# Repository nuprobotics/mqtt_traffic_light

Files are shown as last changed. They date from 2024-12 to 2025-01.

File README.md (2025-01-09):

Review Assignment Due Date (https://classroom.github.com/a/cU98Cs0g)
# Robotics NUP
## MQTT Traffic Light

### Overview
A Traffic light, managed via mqtt protocol based on ESP32C3 controller and WS2821B LED strip.

###  Problem Statement
We need a managed traffic light for our polygon in smart city lab.

### Objectives
- The system has to be stable.
- The traffic light configuration must be changable with minimal human intervention.
- The system must be scalable.

### Features
- Modular structure (interchangable 5,4 and 3 segmented traffic light heads)
- Wifi as a network interface
- Powered by Type-C connector 

### Hardware
ESP32C3
WS2812B 60LED/M  
PETG plastic

### Timeline
- Phase 1 (8.11 - 22.11): MQTT brocker running on a server in the lab, esp32 flashes an LED when triggered through MQTT
- Phase 2 (22.11 - 6.12): The phisical traffic light is designed and assembled
- Phase 3 (6.12 - 20.12): The traffic light is stably running, managed through an MQTT broker

### Team
- Vladimir Shtarev
- Innokentii Meleshchenko

### Risks and Mitigation Strategies

At least two!

| Risk | Impact | Probability | Mitigation Strategy |
| ---| --- | --- | ---|
| No native MQTT support for ESP32C3 | High | Medium | Port MQTT for ESP32 |
| No native WS2812B support for ESP32C3 | High | Low | Port WS2812B driver for ESP32 |
### Success Criteria
- The Traffic light works as an mqtt device
- The traffic light's configuration can be changed in less than 5 minutes
- The traffic light works reliably (no fails during 1 hour continuous test)

### Appendix
The hardware is provided by Vladimir Shtarev

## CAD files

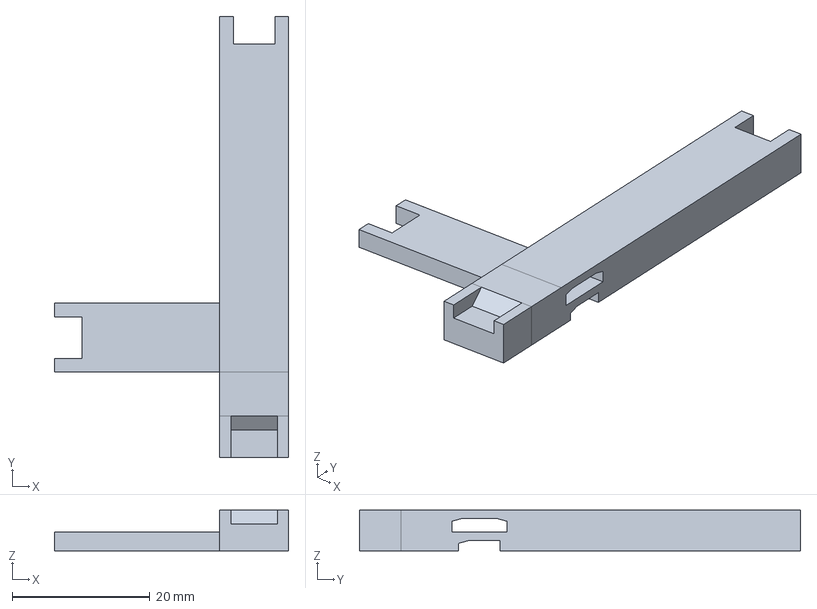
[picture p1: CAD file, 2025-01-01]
CAD_models/traffic_light_head_bare_left.FCStd
34.0 x 64.0 x 5.90 mm

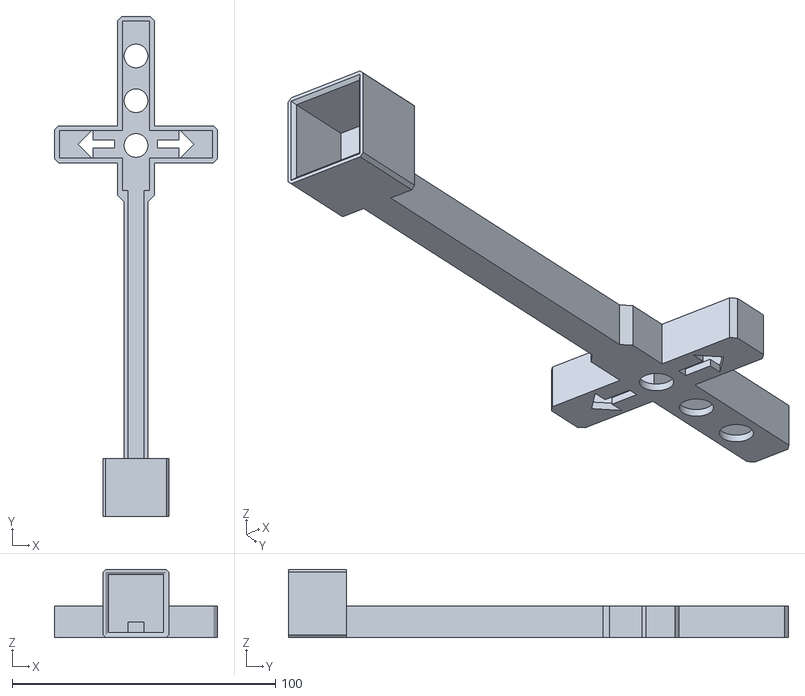
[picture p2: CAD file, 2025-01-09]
Mesh_models/traffic_light_head_case_p1_both.stl
62.0 x 190.0 x 26.0

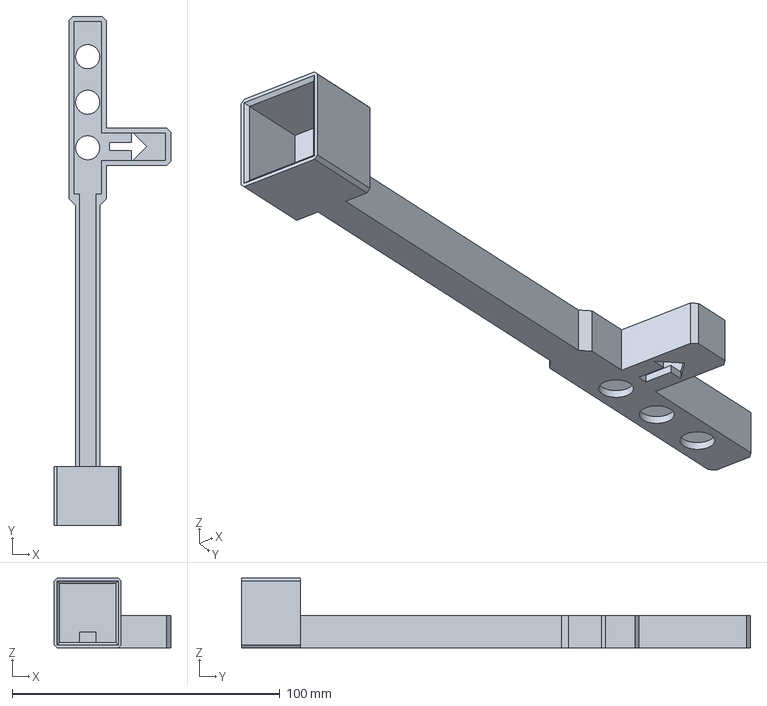
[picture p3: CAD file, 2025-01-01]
CAD_models/traffic_light_head_case_p1_left.FCStd
43.5 x 190.0 x 26.0 mm

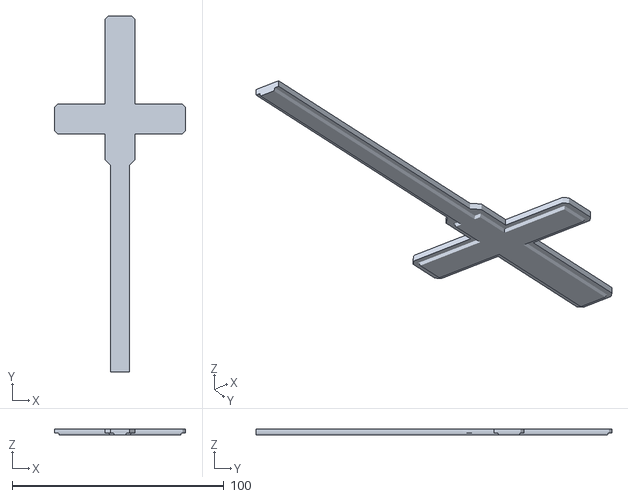
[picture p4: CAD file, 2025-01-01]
Mesh_models/traffic_light_head_case_p2_both.stl
62.0 x 168.0 x 3.00

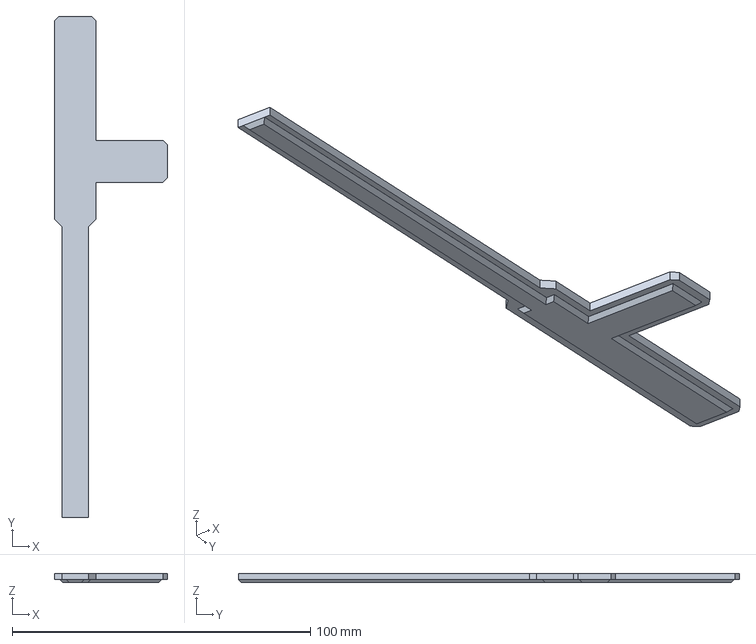
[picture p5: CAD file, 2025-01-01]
CAD_models/traffic_light_head_case_p2_left.FCStd
38.0 x 168.0 x 3.00 mm

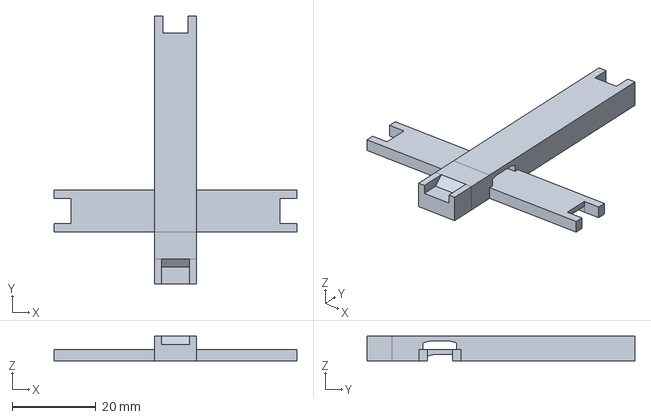
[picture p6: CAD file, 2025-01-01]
CAD_models/traffic_light_head_bare_both.FCStd
58.0 x 64.0 x 5.90 mm

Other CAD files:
Mesh_models/traffic_light_head_case_p2_right.stl
CAD_models/traffic_light_head_case_p1_right.FCStd
Mesh_models/traffic_light_head_bare_left.stl
CAD_models/traffic_light_head_case_p2_both.FCStd
Mesh_models/traffic_light_head_case_p1_left.stl
Mesh_models/traffic_light_head_case_p1_right.stl
CAD_models/traffic_light_head_case_p1_both.FCStd
Mesh_models/traffic_light_head_bare_both.stl
CAD_models/traffic_light_head_case_p2_right.FCStd
Mesh_models/traffic_light_head_bare_right.stl
CAD_models/traffic_light_head_bare_right.FCStd
Mesh_models/traffic_light_head_case_p2_left.stl
CAD_models/base.FCStd
CAD_models/base_lid.FCStd
Mesh_models/base.stl
Mesh_models/base_lid.stl

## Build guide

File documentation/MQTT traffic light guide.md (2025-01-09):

# MQTT Traffic light

## Opening the project in Clion

In order to open the project you have to install PlatformIO core (simply `run $sudo python3 mqtt_traffic_light/Firmware/get-platformio.py`, then install the PlatformIO Clion plugin. If you have any troubles, check official PlatformIO documentation (https://docs.platformio.org/en/latest/core/installation/index.html).
After you have successfully installed PlatformIO core and PlatformIO plugin in CLion, go to Clion tools menu->PlatformIO->PlatformIO Home, go to the PlatformIO Home web page -> Open project -> select mqtt_traffic_light/Firmware -> open -> close the file manager. After that you can open the project in Clion as usual. To build and flash the firmware, simply use the run button in Clion (make sure you have your ESP32C3 connected with a USB-C cable, if it does not work, try pressing the "boot" button before plugging in the cable)

## Project structure

The firmware is built on Arduino framework, so in the main.cpp there are setup() and loop(). There are two classes: TrafficLight and MqttController. In the TrafficLight all the basic logic of state and config is implemented. In the MqttController all the mqtt logic is implemented. 

## Traffic light logic
Traffic light has four possible configurations: MAIN_3_STATE, MAIN_PLUS_RIGHT, MAIN_PLUS_LEFT, MAIN_PLUS_BOTH. As follows from the naming it has either 3 main lights, 1 or 2 side arrows. The main lights can be set to red, yellow and green, while the arrows can be set to off or green. The control is implemented with Adafruit NeoPixel library for WS2812B led strip.

## MQTT logic 
When traffic light is booted, it connects to the Wifi then connects to MQTT broker. As soon as it is connected to the broker it publishes a message to the init topic and collects responses with IDs of active traffic lights during specified timeframe. After that it picks an ID=n+1, where n is the greatest id it collected, that is later published to the same topic. After the traffic light selected it's ID, it subscribes to it's control topic and starts usual operation loop (monitors init topic and announces it's id on request, monitors control topic and responds to requests of changing the configuration or the state.) 
The wifi SSID, password, mqtt address and port, mqtt init topic and mqtt control topic base, as well as the timeframe of recieving id announce responds is specified in the `mqtt_traffic_light/Firmware/src/Config.h` file. 
If you want to use mqtt credentials for connection, simply uncomment corresponding lines in the Config.h file and put your credentials in there, TLS certificate auth is not yet supported.

## Controlling individual traffic lights
To change the config of a specific traffic light, you have to publish a message to the corresponding mqtt control topic:
`SET_CONFIG MAIN_3_STATE` / `SET_CONFIG MAIN_PLUS_RIGHT` /  `SET_CONFIG MAIN_PLUS_LEFT` / `SET_CONFIG MAIN_PLUS_BOTH`

To change the state of a specific traffic light, you have to publish a message to the corresponding mqtt control topic: 
`SET MAIN RED`/`YELLOW`/`GREEN LEFT OFF`/`GREEN RIGHT OFF`/`GREEN`
e.g. `SET MAIN RED LEFT OFF  RIGHT GREEN`

If the state does not match the config, parts not present in the config (e.g. one or both arrows) will simply not be applied, but the others will be. So if you notice, that setting the arrow state does not apply, check the traffic light configuration.

## Assembly
### First you need to get the required hardware:

1. ~82mm (5 LEDs) of WS2812B LED strip 60LED/M
2. ~0.5 meter of thin wire
3. ~130-150mm 3-wire XH2.54 male cable
4. 3-pin XH2.54 female connector
5. 4 M3x10 screws
6. 4 M3 nuts
7. ESP32C3 supermini 
8. 3d-printed parts from mqtt_traffic_light/Mesh_models (i used PETG with 0.6mm nozzle, all parts, except for trafficlight_head_case_p1 are printed without supports). Make sure to set a pause, when printing base.stl, to put the screws inside before the gaps are covered. 
9. Hot glue 
10.  Soldering tools
11. Super glue 
12. A little bit of Double-sided tape
13. A little bit of regular tape

### Assembly steps:
1. Glue the **XH2.54 female connector** into the **base_lid** part, so it is flush with the bottom side of it. 
2. Solder the  **XH2.54 female connector** to the 5V, GND, GPIO4 pins of the **ESP32C3**. 
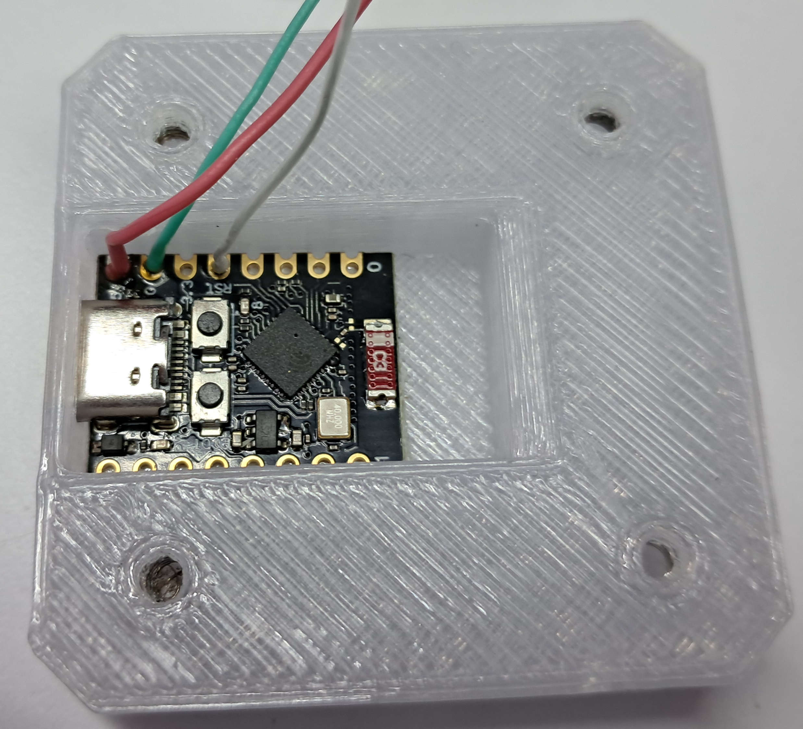
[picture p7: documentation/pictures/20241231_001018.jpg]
3. Use double-sided tape to fix the **ESP32C3** in the **base** part, so the USB-C port is inside the corresponding slot and is easily accessible from the outside.
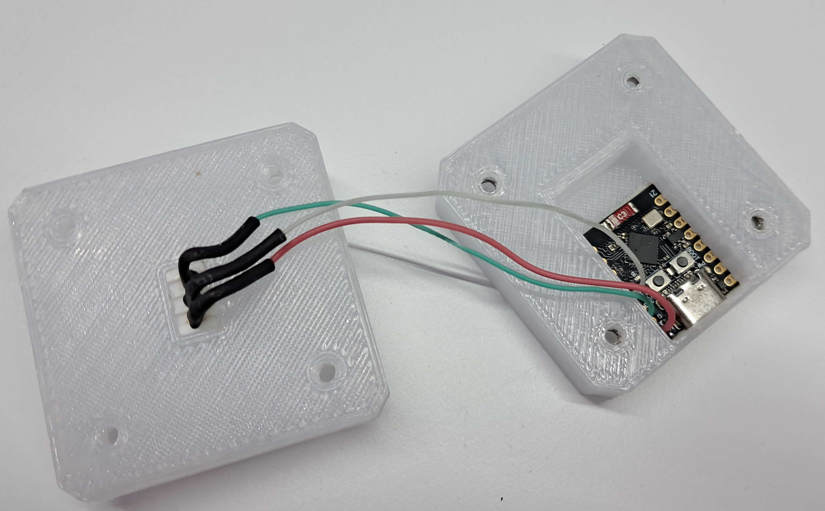
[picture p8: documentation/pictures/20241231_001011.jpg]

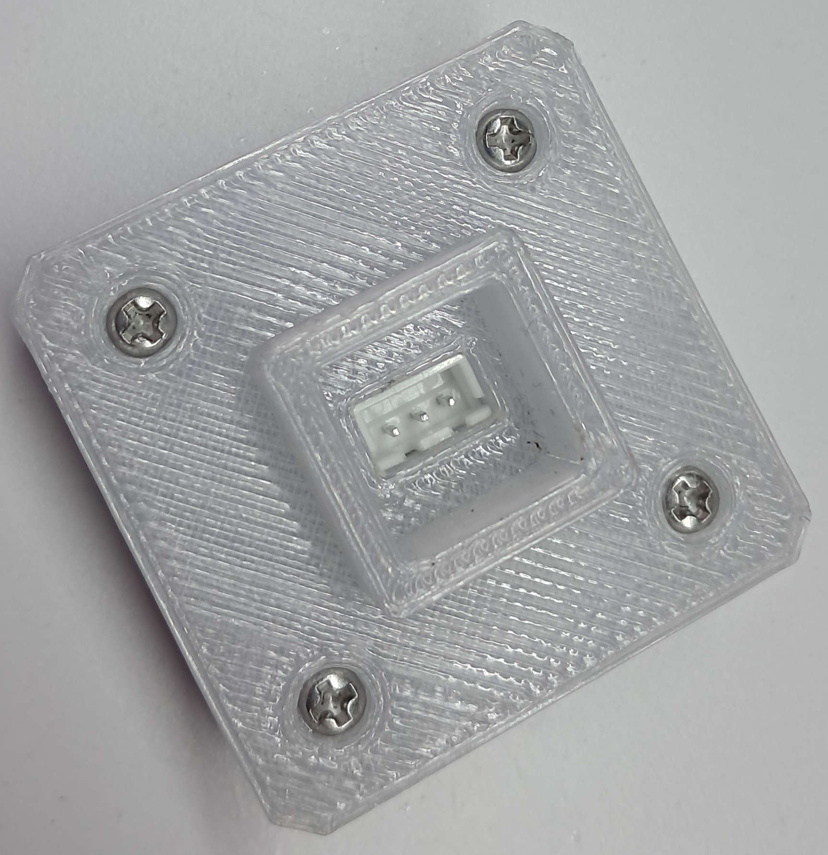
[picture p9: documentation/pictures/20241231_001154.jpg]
4. Screw the **base_lid** to the **base** part.
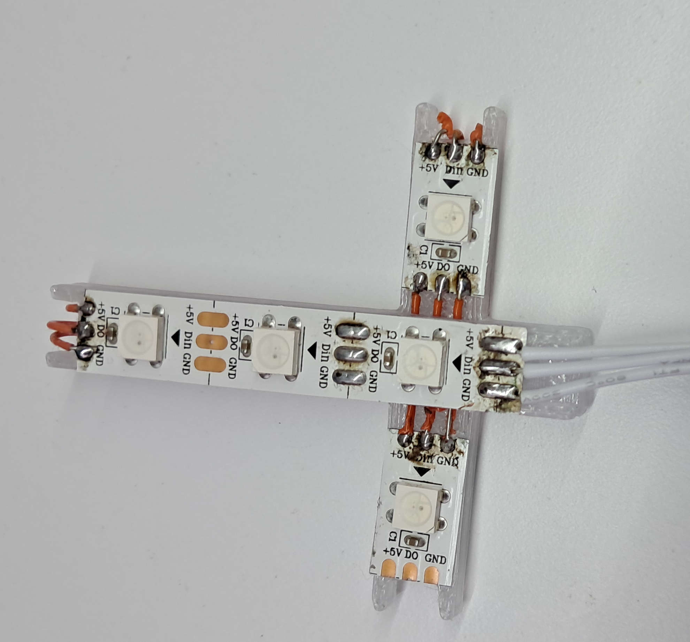
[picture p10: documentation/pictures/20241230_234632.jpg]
5. Asseble the core of the traffic light head using the **traffic_light_head_bare** part, WS2812B, thin wire and the **3-wire XH2.54 male cable**. Make sure the pinout of all the **WS2812B** strips matches the pinout of the **ESP32C3** with the **XH2.54 female connector**.
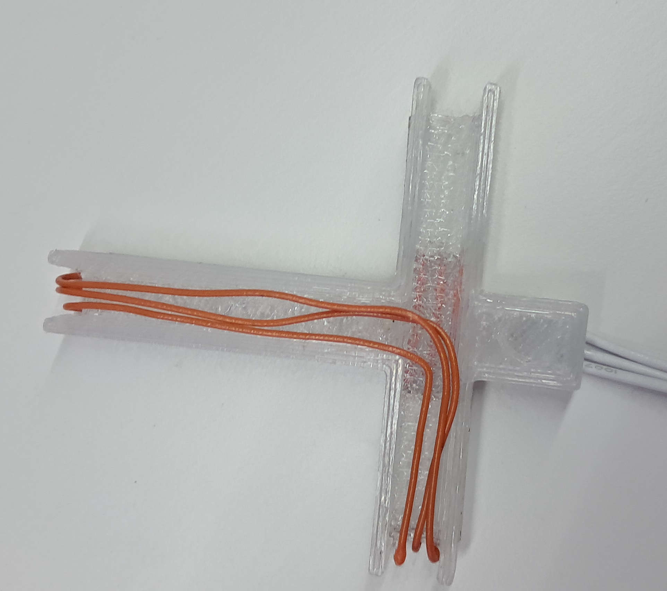
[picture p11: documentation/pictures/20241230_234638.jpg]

6. Cover the holes for the lights of the **traffic_light_head_case_p1** with regular tape, and pour hot glue in the holes. The hot glue shoul be flush with both sides of the part. Wait for the hot glue to cool down.
7. Insert the core of the traffic light head into the **traffic_light_head_case_p1** part. It does not matter if it is not alligned perfectly, it is also not supposed to be flush with the back side of the **traffic_light_head_case_p1**.
8. Insert the **traffic_light_head_case_p2** into the **traffic_light_head_case_p1**, if it is not fixed by friction, use some super glue. 
9. Connect the **3-wire XH2.54 male cable** to the **XH2.54 female connector**. Put the Traffic light head fixture onto the **base_lid**. 
10.  Power on the Traffic light and check if it works correctly (use UART monitor for logs and send a state command to the corresponding topic to check the LEDS. If the LEDS do not turn on, but the logs are ok and you have sent the change state command, probably you have faulty wiring.).

11.* The **traffic_light_head_bare**, **traffic_light_head_case_p1** and **traffic_light_head_case_p2** are supposed to be selected based on the traffic light configuration you want to use: e.g. for MAIN_PLUS_BOTH use parts with "both" at the end. The wiring should be changed accordingly: For single arrow configs, the arrow data input is connected directly to the main strip output and for both arrows, the right one is connected first, and the left one is connected to the right one.

## Congratulations, now you can build your own small-scale traffic light system with as many different traffic lights as you want.

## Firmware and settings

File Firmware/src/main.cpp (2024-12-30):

#include "TrafficLight.h"
#include "MqttController.h"

TrafficLight trafficLight(TrafficLightConfiguration::MAIN_PLUS_BOTH);
MqttController mqttController(trafficLight);

void setup() {
    Serial.begin(115200);
    delay(1000);
    pinMode(LED_PIN, OUTPUT);
    mqttController.begin();
    Serial.println("Finished setup, starting main loop...");
}

void loop() {
    mqttController.loop();
}

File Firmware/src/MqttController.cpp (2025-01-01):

#include "MqttController.h"

MqttController::MqttController(TrafficLight& trafficLight)
    : m_light(trafficLight),
      m_mqttClient(m_wifiClient),
      m_trafficLightId(0),
      m_isActive(false),
      m_initStartTime(0)
{
    // Empty
}

void MqttController::begin() {
    connectWiFi();

    m_mqttClient.setServer(MQTT_ADDRESS, MQTT_PORT);
    // Attach the callback function for incoming MQTT messages
    m_mqttClient.setCallback([this](const char* topic, const byte* payload, const unsigned int length){
        this->onMqttMessage(topic, payload, length);
    });

    // Start the ID negotiation
    m_isActive = false;
    m_initStartTime = millis();
    m_knownIds.clear();
    m_trafficLightId = 0;  // Means we don't have an ID yet

    connectMQTT();
    // Publish a message saying we're NEW and listening for existing IDs
    publishInitRequest();
}

void MqttController::loop() {
    // Maintain MQTT connection
    if (!m_mqttClient.connected()) {
        connectMQTT();
    }
    m_mqttClient.loop();
    // If we aren't active yet, check if we need to finalize ID assignment
    if (!m_isActive) {
        const unsigned long elapsed = millis() - m_initStartTime;
        if (elapsed >= ID_COLLECTION_TIME_MS) {
            checkAndAssignId();
        }
    }
}
// Example: using ESP32's chip-specific ID / MAC
String MqttController::generateMqttClientId() {
    // For ESP32 Arduino, you can get chip ID or MAC
    // In a typical ESP32 (not ESP32-C3), we might do something like:
    //   uint64_t chipid = ESP.getEfuseMac();
    // For ESP32-C3, you can read the MAC similarly:

    uint8_t mac[6];
    esp_read_mac(mac, ESP_MAC_WIFI_STA);  // read station mac
    char buf[30];
    snprintf(buf, sizeof(buf),
             "TrafficLight_%02X%02X%02X%02X%02X%02X",
             mac[0], mac[1], mac[2], mac[3], mac[4], mac[5]);
    return {buf};
}

void MqttController::connectWiFi() {
    Serial.print("Connecting to Wi-Fi: ");
    Serial.print(WIFI_SSID);

    char ssid[] = WIFI_SSID;
    char passwd[] = WIFI_PASSWD;
    WiFi.begin(ssid, passwd);

    while (WiFiClass::status() != WL_CONNECTED) {
        delay(500);
        Serial.print(".");
    }
    Serial.println(".");
    Serial.println("Wi-Fi connected.");
    Serial.print("IP address: ");
    Serial.println(WiFi.localIP());
}

void MqttController::connectMQTT() {
    while (!m_mqttClient.connected()) {
        Serial.print("Attempting MQTT connection to ");
        Serial.print(MQTT_ADDRESS);
        Serial.print("...");
        String clientId = generateMqttClientId();
        Serial.print("ClientID: ");
        Serial.println(clientId);


        #ifndef MQTT_LOGIN
        // Connect without auth
        if (m_mqttClient.connect(clientId.c_str())) {
            Serial.println("connected!");
            // Subscribe to the init topic unconditionally (we need to respond to new lights)
            m_mqttClient.subscribe(MQTT_INIT_TOPIC);
        } else {
            Serial.print("failed, rc=");
            Serial.print(m_mqttClient.state());
            Serial.println("; trying again in 2 seconds");
            delay(2000);
        }
        #else
        // Connect with auth from Config.h
        if (m_mqttClient.connect(clientId.c_str(), MQTT_LOGIN, MQTT_PASSWORD)) {
            Serial.println("connected!");
            // Subscribe to the init topic unconditionally (we need to respond to new lights)
            m_mqttClient.subscribe(MQTT_INIT_TOPIC);
        } else {
            Serial.print("failed, rc=");
            Serial.print(m_mqttClient.state());
            Serial.println("; trying again in 2 seconds");
            delay(2000);
        }
        #endif
    }
}

void MqttController::onMqttMessage(const char* topic, const byte* payload, const unsigned int length) {
    const String topicStr(topic);
    String message;
    for (unsigned int i=0; i<length; i++) {
        message += static_cast<char>(payload[i]);
    }

    // If this is the init topic
    if (topicStr == MQTT_INIT_TOPIC) {
        processInitMessage(message);
    }
    // If it's our control topic
    else if (m_isActive) {
        // Our control topic is something like: "trafficlights/control/<id>"
        const String controlTopic = String(MQTT_CONTROL_TOPIC) + String(m_trafficLightId);
        if (topicStr == controlTopic) {
            processControlMessage(message);
        }
    }
}

// We publish a "NEW" message so active lights will respond with their ID
void MqttController::publishInitRequest() {

    // For instance: "NEW"
    // You could embed your MAC address or partial ID for reference
    m_mqttClient.publish(MQTT_INIT_TOPIC, "NEW");
    // Also subscribe to the init topic (to see active lights responding)
    m_mqttClient.subscribe(MQTT_INIT_TOPIC);
    Serial.println("[MQTT] Published init request: NEW");
    Serial.println("Waiting for init responses...");
}

// We respond to another light's "NEW" request with "ACTIVE_ID=<myId>"
void MqttController::publishInitResponse() {
    if (!m_mqttClient.connected() || !m_isActive) return;
    char msg[32];
    snprintf(msg, sizeof(msg), "ACTIVE_ID=%d", m_trafficLightId);
    m_mqttClient.publish(MQTT_INIT_TOPIC, msg);
    Serial.print("[MQTT] Published init response: ACTIVE_ID=");
    Serial.println(m_trafficLightId);
}

void MqttController::processInitMessage(const String& message) {
    // If we see "NEW" from someone else, and we are active, we should respond with our ID
    if (message == "NEW") {
        if (m_isActive) {
            // respond with "ACTIVE_ID=<myId>"
            Serial.println("[MQTT] Received init request, responding...");
            publishInitResponse();
        }
    }
    // If we see something like "ACTIVE_ID=3" from an existing light while we are collecting IDs
    else if (message.startsWith("ACTIVE_ID=")) {
        const String idPart = message.substring(9); // get the substring after 'ACTIVE_ID='
        const int existingId = idPart.toInt();
        Serial.print("[MQTT] Received init response, id announced: ");
        Serial.println(existingId);
        m_knownIds.push_back(existingId);
        Serial.print("[MQTT] Got active ID, added to known ids: ");
        Serial.println(existingId);
    }
}

void MqttController::checkAndAssignId() {
    // We have finished collecting IDs, so pick the largest + 1
    // If no known IDs, we become ID=1
    int maxId = -1;
    for (int id : m_knownIds) {
        Serial.println(id);
        if (id > maxId) maxId = id;
    }
    m_trafficLightId = maxId + 1;
    m_isActive = true;

    // Now subscribe to our control topic
    subscribeToControlTopic();

    Serial.print("[MQTT] Assigned new ID: ");
    Serial.println(m_trafficLightId);
    publishInitResponse();
}
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

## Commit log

2024-11-22 added datasheet on esp32 C3
2024-11-23 designed the base of the traffic light
    [base.FCStd, base.stl, base_lid.FCStd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]
2024-12-30 updated 3d models, added instructions to the documentation
    [traffic_light_head_bare_both.FCStd, traffic_light_head_bare_both.stl, traffic_light_head_case_p1_both.FCStd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]
2025-01-01 added 3d models for different configurations
    [traffic_light_head_bare_left.FCStd, traffic_light_head_bare_left.stl, traffic_light_head_bare_right.FCStd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]
2025-01-09 fixed printing instructions
2025-01-09 fixed traffic_light_head_case_p1_both.stl 3d model
    [traffic_light_head_case_p1_both.stl]
